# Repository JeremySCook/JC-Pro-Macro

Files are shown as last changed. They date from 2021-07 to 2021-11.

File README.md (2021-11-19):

# JC-Pro-Macro

Macro keypad and rotary input based on the ATmega32U4 Pro Micro

Enhanced JC Pro Macro 2: https://github.com/JeremySCook/JC-Pro-Macro-2/

**!! After initial install, GND and RST pins may need to be shorted together  
momentarily to reset after hitting upload in the Arduino IDE for reprogramming.  
Quickly resetting twice in sequence may give you more time to load the program !!**

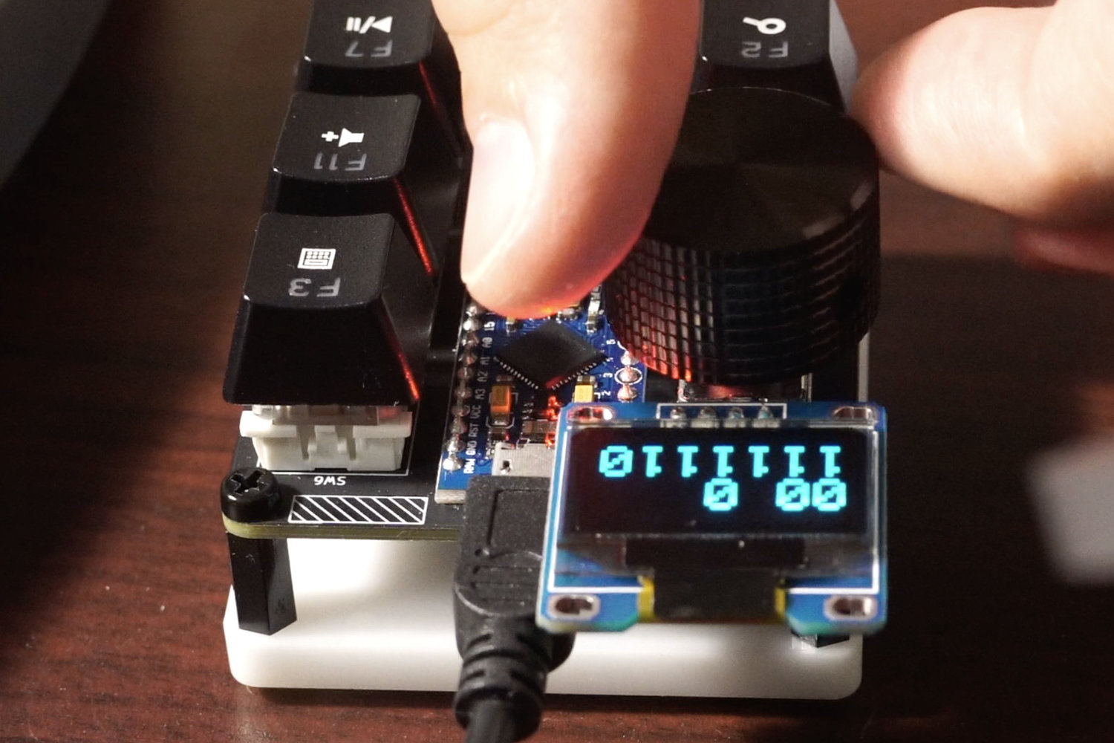
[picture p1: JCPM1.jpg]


# Videos:

Development:       https://www.youtube.com/watch?v=g-XJLiv03rI  
Assembly process:  https://www.youtube.com/watch?v=au07GKwa_J8

# Info

Available on Tindie: https://www.tindie.com/products/24327

I2C pins are broken out and arranged for use with SSD1306-based OLED screens  
Current program includes diagnostic code for this type of screen.  
2 additional GPIO pins, as well as GND and +5V are broken out, giving a total  
of 4 GPIO pins that can be used to control external devices (perhaps a small fan)



Uses HID Project software by NicoHood: https://github.com/NicoHood/HID  
My previous rotary input project: https://github.com/JeremySCook/RotaryControl



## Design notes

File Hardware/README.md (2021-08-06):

Assembly video: https://www.youtube.com/watch?v=VwfGT706jW0

Items required:

JC Pro Macro Board [Tindie](https://www.tindie.com/products/24327)  
EC11 - style rotary encoder [Amazon](https://amzn.to/2UHf1wW)  
KeySwitches - [Amazon](https://amzn.to/3iFpGQH)  
"Arduino" Pro Micro - [Amazon](https://amzn.to/2UALftK)

Depending on preference, and for potentially better performance, user may choose to desolder  
or otherwise **disable LEDs** (or lack thereof) on the Pro Micro as shown below:

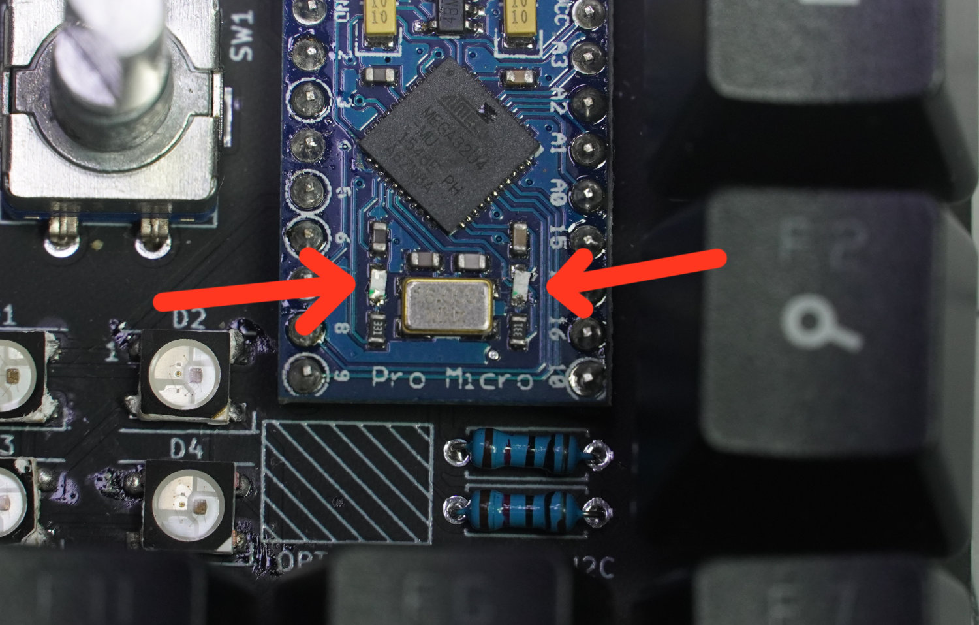
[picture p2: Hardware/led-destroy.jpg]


A variety of keyswitches and encoders will work, examples are provided for your reference.
The Pro Micro is available on Tindie, along with some other components.

As shown in the video, you can even take apart a keyboard to harvest parts if you like.

Amazon links are affiliate, meaning I get a small percentage of sales.

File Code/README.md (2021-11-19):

## Programming

**!! After initial install, GND and RST pins may need to be shorted together  
momentarily to reset after hitting upload in the Arduino IDE for reprogramming.
Quickly resetting twice in sequence may give you more time to load the program !!**

## Standard Code

Current standard code (ProMacroStandard.ino) is written and tested on a Macintosh -  
should work with a PC or Linux, possibly with some modifications.

Includes a mode for media control and browser tabbing, as well as a "jiggle" mode to keep your computer awake.
Switch modes by simultaneously pressing upper-right key, and the key directly below that.

Also, due to differences in manufacture, line 50:

Encoder myEnc(0,1); //if rotation is backwards, swap 0 and 1

may need to be swapped as noted depending on the encoder

## Alternative Modes Slihter.io Mode & FCPX

Additional modes are included in the standard code and can be accessed by modifying the array shown below. Modes  
will switch from the 0 indexed number in the array, to the next one and so forth. So if you want your controller to  
go: volume-jiggle-slither, change it to {0, 1, 2}. volume-FCPX would be {0, 3}. All current modes would be {0, 1, 2, 3, 4}



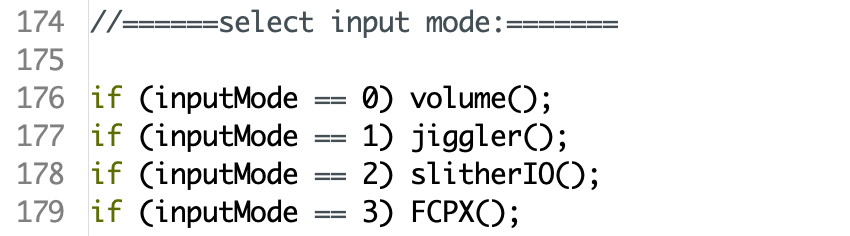
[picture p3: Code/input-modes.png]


In slither mode, align the mouse with the head of worm and press upper-right keyboard button. You can then steer the 
worm with the encoder and speed up with the three bottom buttons. There's also a "NASCAR" mode where the worm keeps
turning left.

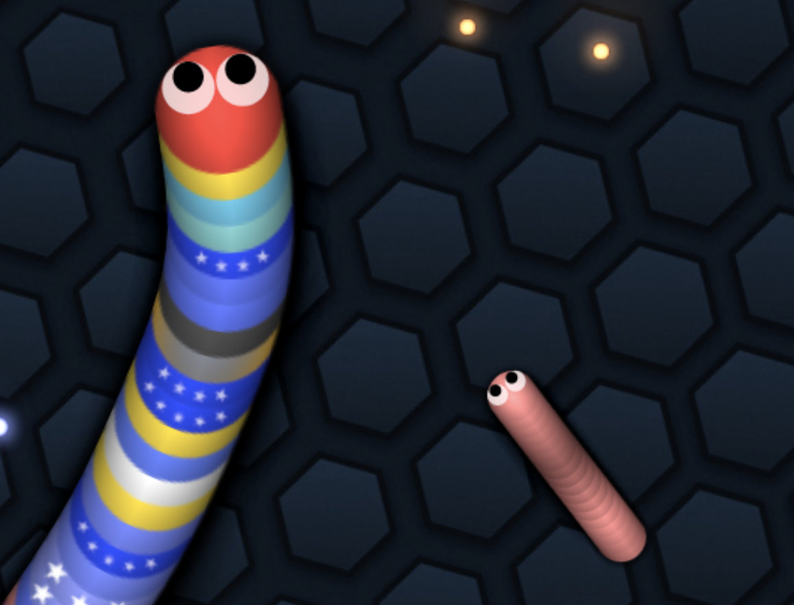
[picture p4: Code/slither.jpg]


In FCPX mode, encoder advances/rewinds frames, bottom buttons stop ffwd/rev, top right and below zoom in and out. Press
the encoder to break all clips. Great for trimming extra footage.

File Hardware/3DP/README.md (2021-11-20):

JC Pro Macro Model.step is the assembly 3D file that is openable in a variety of CAD packages.  
Not particularly "clean" but potentially good for reference if you want to build on the design.

**3D printed accessories for JCPM**

* 3DP-base - can be used as a base instead of standoffs and laser cut acrylic - may need work on tabs.
* Assembl-Jig - used to facilitate assembly of device
* Knob - 3D-printed knob for EC11 encoder
* PR-giganto-knob - as pictured below, made by [Pat Regan](https://twitter.com/patsheadcom) via [customizer](https://www.thingiverse.com/thing:2220561)
* 3DP-base_m3_heatset_flaszlo11.stl, made by flaszlo11

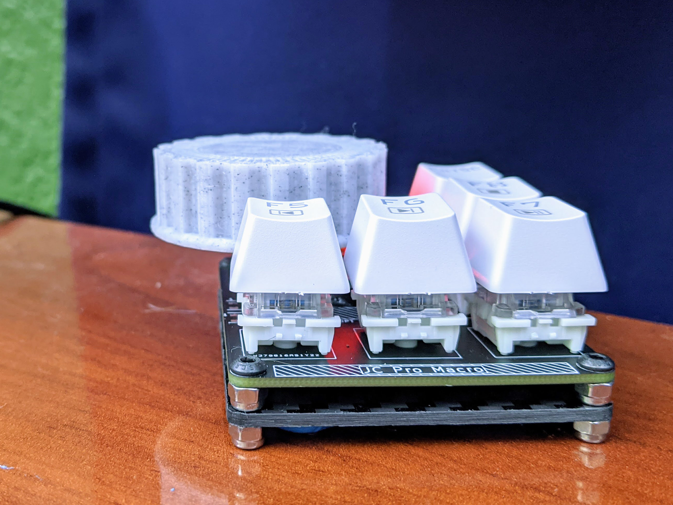
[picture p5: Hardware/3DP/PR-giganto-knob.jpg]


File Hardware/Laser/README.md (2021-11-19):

Laser cut base options for LightBurn (outline is slightly larger than board)

DXF is the board layout itself.

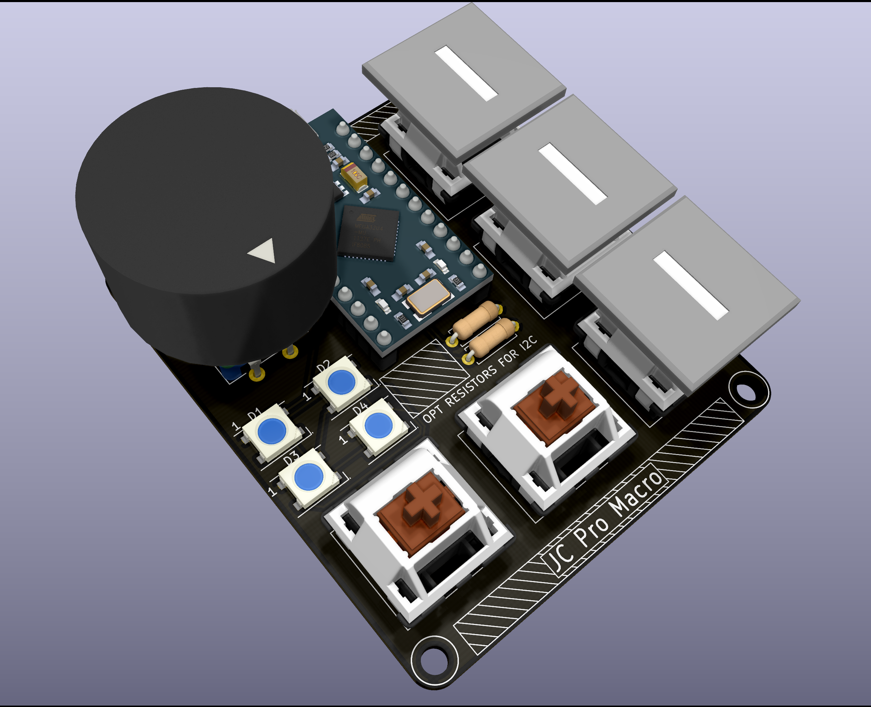
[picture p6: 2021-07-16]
JCPMRender.png

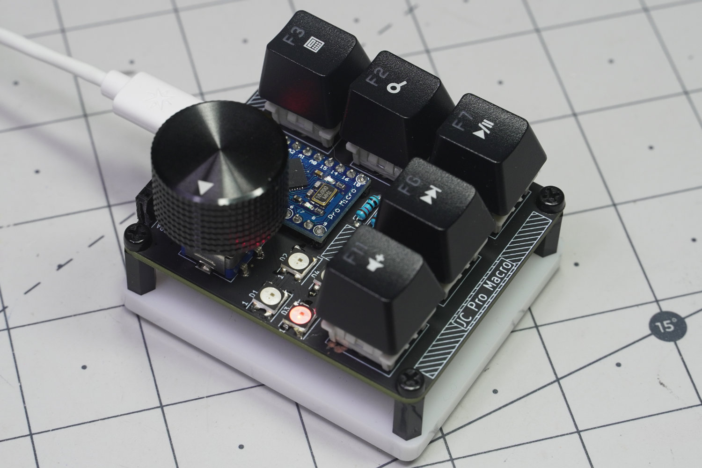
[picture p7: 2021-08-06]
JCPM2.jpg

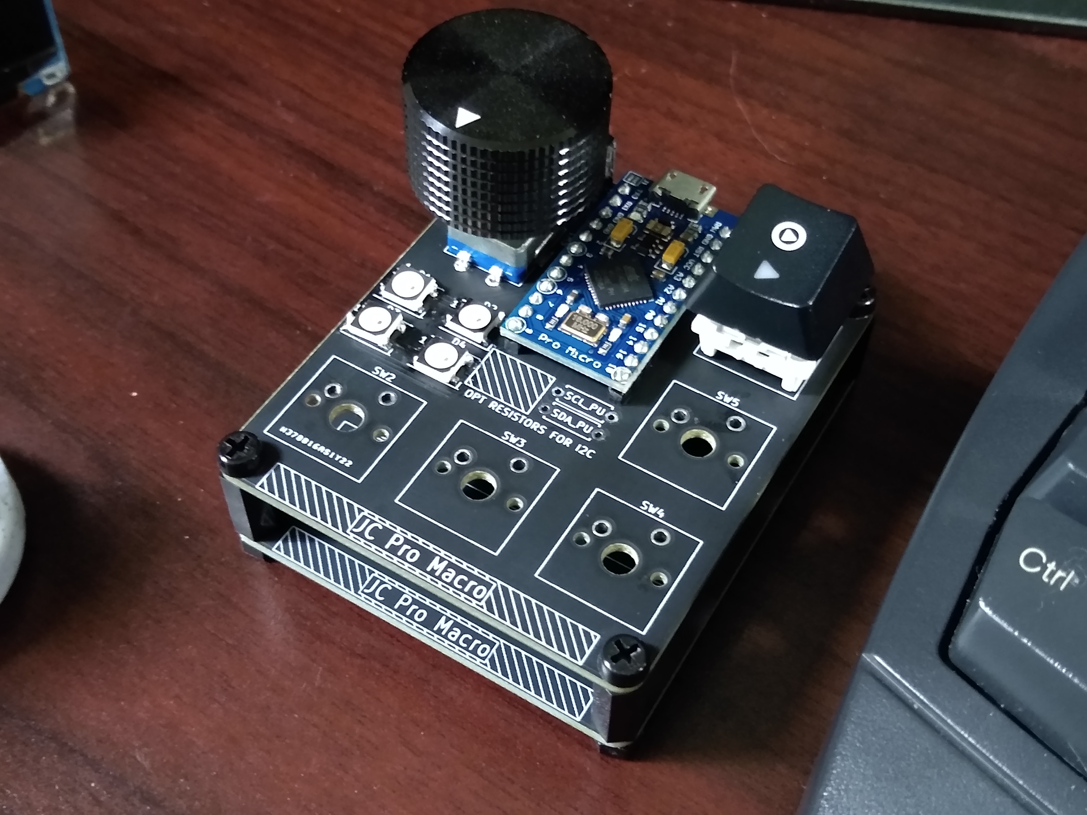
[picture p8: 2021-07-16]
JCPMPartAssy.jpg

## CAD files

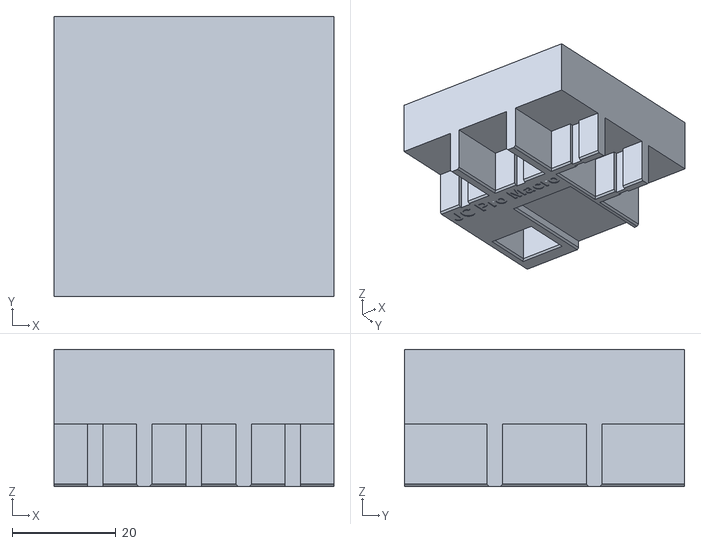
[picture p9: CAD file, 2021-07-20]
Hardware/3DP/Assembly-Jig.stl
54.0 x 54.1 x 26.5

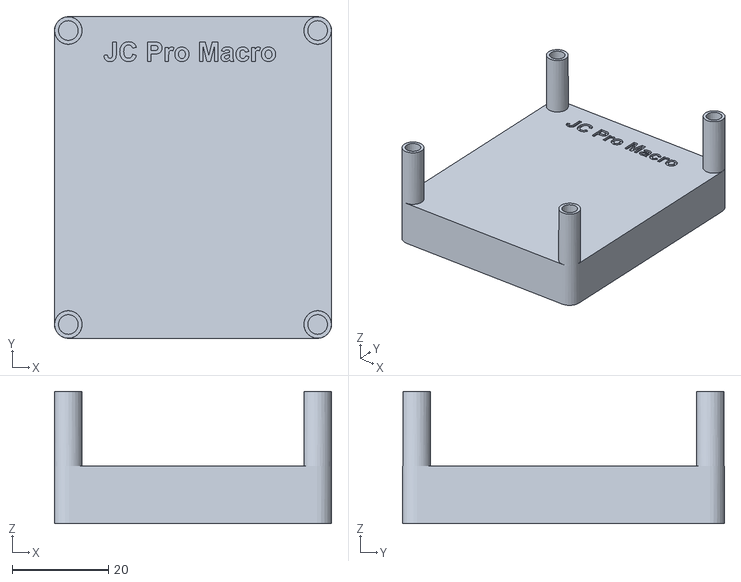
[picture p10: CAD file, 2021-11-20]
Hardware/3DP/3DP-base_m3_heatset_flaszlo11.stl
57.7 x 67.0 x 27.5

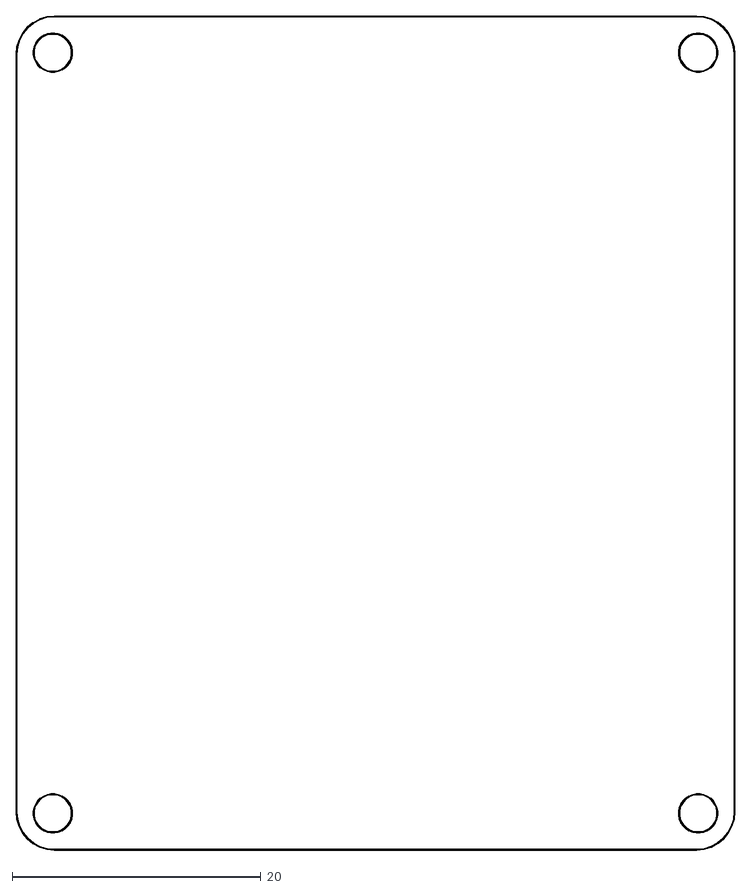
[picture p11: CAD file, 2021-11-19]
Hardware/Laser/JC Pro Macro Board Cuts.dxf
57.8 x 67.0

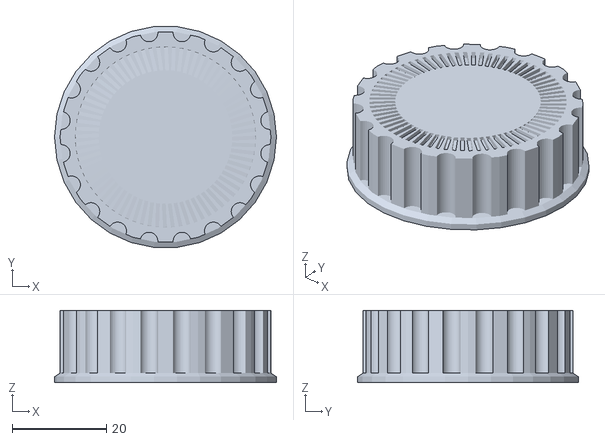
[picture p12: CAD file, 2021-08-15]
Hardware/3DP/PR-gitanto-knob.stl
47.0 x 46.7 x 15.2

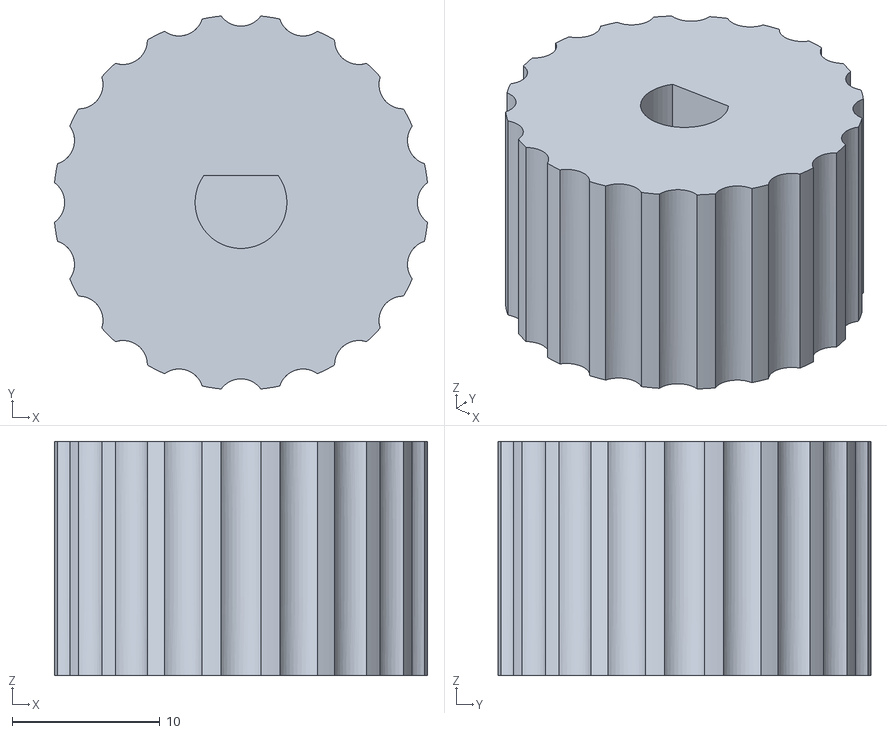
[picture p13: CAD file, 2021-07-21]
Hardware/3DP/Knob.stl
25.3 x 25.3 x 15.9

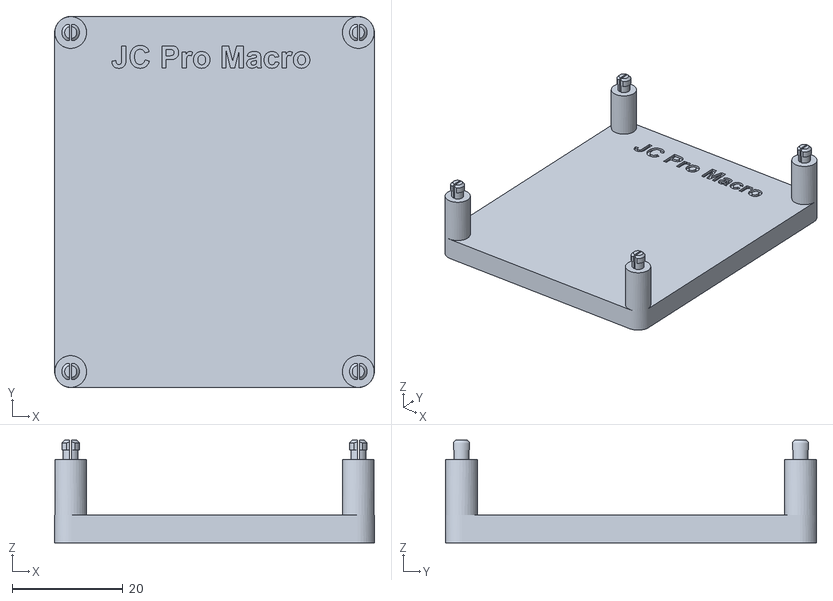
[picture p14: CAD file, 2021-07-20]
Hardware/3DP/3DP-base.stl
57.7 x 67.0 x 18.5

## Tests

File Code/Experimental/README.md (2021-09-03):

## Experimental Code

## Experimental Music Mode

ProMacro-6-music.ino allows you to connect a small speaker to GPIO pin 7 to play a number of notes.
Demo: https://twitter.com/JeremySCook/status/1423705079153139716

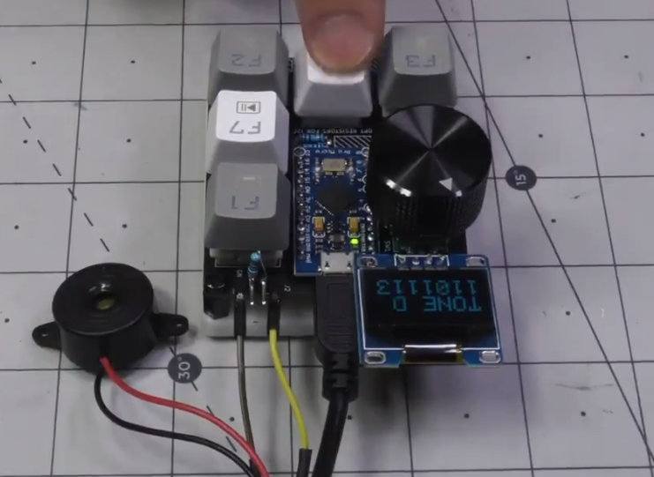
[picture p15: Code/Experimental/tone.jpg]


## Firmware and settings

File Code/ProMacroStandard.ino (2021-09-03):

//Example for JC Pro Macro board
//set up to work in Mac OS
//Includes support for 1306 display
//Reference: https://github.com/NicoHood/HID/blob/master/src/KeyboardLayouts/ImprovedKeylayouts.h
//Reference: https://arduinogetstarted.com/tutorials/arduino-button-long-press-short-press 
//
//To do:
//Figure out what to do with bottom support - remake offset so locks in?
//caps lock code? - does not work properly on Mac it seems

//========================================================

#include <SPI.h>
#include <Wire.h>

// Declare variables etc=========================================

bool SW1 = 1; //encoder button
bool SW2 = 1; //lower-left keyswitch
bool SW3 = 1;
bool SW4 = 1; //lower-right keyswitch
bool SW5 = 1;
bool SW6 = 1; //upper-right keyswitch
bool increment = 0;
bool decrement = 0;
long oldPosition;
long newPosition;
int inputMode = 0;
int LEDLight = 1;
int LEDCircle[4] = {0, 1, 3, 2};
int counter = 0;
bool nascar = 0;
long newNascarTurnTime = 0;
long oldNascarTurnTime = 0;
long newBeatTime = 0;
long oldBeatTime = 0;
bool beatOn = 0;

int fanSpeed = 0;
bool fanPulse = 0;
long newPulseTime = 0;
long oldPulseTime = 0;
int fanRPM = 0;
char toneNote;

int modeArray[] = {0, 1}; //adjust this array to modify sequence of modes - as written, change to {0, 1, 2, 3, 4, 5} to access all modes
int inputModeIndex = 0;
int modeArrayLength = (sizeof(modeArray) / sizeof(modeArray[0]));

// Encoder setup =============================================

#include <Encoder.h>
#include <HID-Project.h>
Encoder myEnc(0,1); //if rotation is backwards, swap 0 and 1

// Screen setup =============================================

#include <Adafruit_GFX.h>
#include <Adafruit_SSD1306.h>
#define SCREEN_WIDTH 128 // OLED display width, in pixels
#define SCREEN_HEIGHT 64 // OLED display height, in pixels
#define OLED_RESET     4 // Reset pin # (or -1 if sharing Arduino reset pin)
#define SCREEN_ADDRESS 0x3C ///< See datasheet for Address; 0x3D for 128x64, 0x3C for 128x32
Adafruit_SSD1306 display(SCREEN_WIDTH, SCREEN_HEIGHT, &Wire, OLED_RESET);

// NeoPixel setup =============================================

// NeoPixel Ring simple sketch (c) 2013 Shae Erisson
// Released under the GPLv3 license to match the rest of the
// Adafruit NeoPixel library

#include <Adafruit_NeoPixel.h>
#ifdef __AVR__
 #include <avr/power.h> // Required for 16 MHz Adafruit Trinket
#endif

// Which pin on the Arduino is connected to the NeoPixels?
#define PIN        5 // On Trinket or Gemma, suggest changing this to 1

// How many NeoPixels are attached to the Arduino?
#define NUMPIXELS 4 // Popular NeoPixel ring size

// When setting up the NeoPixel library, we tell it how many pixels,
// and which pin to use to send signals. Note that for older NeoPixel
// strips you might need to change the third parameter -- see the
// strandtest example for more information on possible values.
Adafruit_NeoPixel pixels(NUMPIXELS, PIN, NEO_GRB + NEO_KHZ800);

#define DELAYVAL 500 // Time (in milliseconds) to pause between pixels

//============================================================

void setup() {
  Serial.begin(9600);
  pinMode(4, INPUT_PULLUP); //SW1 pushbutton (encoder button)
  pinMode(15, INPUT_PULLUP); //SW2 pushbutton
  pinMode(A0, INPUT_PULLUP); //SW3 pushbutton
  pinMode(A1, INPUT_PULLUP); //SW4 pushbutton
  pinMode(A2, INPUT_PULLUP); //SW5 pushbutton
  pinMode(A3, INPUT_PULLUP); //SW6 pushbutton

  randomSeed(analogRead(A9));
     
  // SSD1306_SWITCHCAPVCC = generate display voltage from 3.3V internally
  if(!display.begin(SSD1306_SWITCHCAPVCC, SCREEN_ADDRESS)) {
    Serial.println(F("SSD1306 allocation failed"));
    for(;;); // Don't proceed, loop forever
  }
  display.setRotation(2); //sets rotation 1 through 4 (2 = 180º rotation vs 4)
  display.clearDisplay();
  // Draw text
  display.setTextSize(1);             // Normal 1:1 pixel scale
  display.setTextColor(SSD1306_WHITE);        // Draw white text
  display.setCursor(30,0);             // Start at top-left corner
  display.print("Hello, world!");
  display.setCursor(30,30);  
  display.print("test");
  display.display();
  delay(10);
  display.setTextSize(3); 

//setup keyboard and mouse input
//perhaps cound add in a delay so that you can program before this starts up
Mouse.begin();
Keyboard.begin();
//BootKeyboard.begin(); - BootKeyboard use appears to give problems w/ Macintosh


//NeoPixel setup=========================================

  pixels.begin(); // INITIALIZE NeoPixel strip object (REQUIRED)
  pixels.clear();


  for(int i=0; i<NUMPIXELS; i++){
    pixels.setPixelColor(i, pixels.Color(10, 0, 0));
  }
  pixels.show(); // Show results
}


void loop() {

  SW1 = digitalRead(4);
  SW2 = digitalRead(15);
  SW3 = digitalRead(A0);
  SW4 = digitalRead(A1);
  SW5 = digitalRead(A2);
  SW6 = digitalRead(A3);

  newPosition = myEnc.read();
  
  if (newPosition > (oldPosition + 2)) { 
    increment = 1;
    delay(5);
    oldPosition = myEnc.read();
  }
  if (newPosition < (oldPosition - 2)) {
    decrement = 1;
    delay(5);
    oldPosition = myEnc.read();
  }

//=========change mode=================

   if ((SW6 == 0) && (SW5 == 0)){ 
      if (inputModeIndex < modeArrayLength){
        inputModeIndex++;
        inputMode = modeArray[inputModeIndex];
      }
      if (inputModeIndex == modeArrayLength){
        inputModeIndex = 0;
        inputMode = modeArray[inputModeIndex];
      }
      SW6 = 1;
      SW5 = 1;
      delay(250);
    }

//================================

//screen(); //need to change to only call within functions

//======select input mode:=======

if (inputMode == 0) volume();
if (inputMode == 1) jiggler();
if (inputMode == 2) slitherIO();
if (inputMode == 3) FCPX();
if (inputMode == 4) fan();
if (inputMode == 5) music();

//Serial.println(inputMode);

}

void volume(){ //works with new code

  if (increment == 1) {
        Consumer.write(MEDIA_VOLUME_UP);
        if (LEDLight == 3) LEDLight = 0;
        else if (LEDLight < 3) LEDLight += 1;
        pixels.clear();
        pixels.setPixelColor(LEDCircle[LEDLight], pixels.Color(10, 0, 0));
        pixels.show(); // Show results
        increment = 0;
        decrement = 0;
        //delay(10);
      }
      
  if (decrement == 1) {
        Consumer.write(MEDIA_VOLUME_DOWN);
        if (LEDLight == 0) LEDLight = 3;
        else if (LEDLight > 0) LEDLight -= 1;
        pixels.clear();
        pixels.setPixelColor(LEDCircle[LEDLight], pixels.Color(10, 0, 0));
        pixels.show(); // Show results
        increment = 0;
        decrement = 0;
        //delay(10);
      }
  if (SW6 == 0){ //tab to next browser tab Firefox or Chrome
        Keyboard.press(KEY_LEFT_CTRL);
        Keyboard.press(KEY_TAB);          
        Keyboard.releaseAll();
        delay(50);
      }
  if (SW5 == 0){ //tab to previous browser tab Firefox or Chrome
        Keyboard.press(KEY_LEFT_SHIFT);
        Keyboard.press(KEY_LEFT_CTRL);
        Keyboard.press(KEY_TAB);
        Keyboard.releaseAll();
        delay(50);
      }
  if (SW4 == 0) {
        Consumer.write(MEDIA_PLAY_PAUSE); 
        delay(100);
      }
  if (SW3 == 0) {
        Consumer.write(MEDIA_NEXT);
        delay(50);
      }
  if (SW2 == 0) {
        Consumer.write(MEDIA_PREVIOUS);
        delay(50);
      }
screen();
}

void jiggler(){ //works with new code
  
  Serial.print("commence to jiggling");
      //Consumer.write(MEDIA_VOLUME_UP);
      //Consumer.write(MEDIA_VOLUME_DOWN);
      long randNumber = random(-50, 50);
      long randNumber1 = random(-50, 50);
      long randNumber2 = random(-50, 50);
      Mouse.move(randNumber, randNumber1);
      delay(100);
      int xMap = map(randNumber, -50, 50, 0, 100);
      int yMap = map(randNumber1, -50, 50, 0, 100);
      int zMap = map(randNumber2, -50, 50, 0, 100);
      pixels.setPixelColor(0, pixels.Color(xMap, yMap, zMap));
      pixels.setPixelColor(2, pixels.Color(zMap,xMap,yMap));
      pixels.setPixelColor(1, pixels.Color(yMap, zMap, xMap));
      pixels.setPixelColor(3, pixels.Color(xMap, zMap, yMap));           
      pixels.show(); // Show results

screenJiggle(); 
    
}

void slitherIO(){ //works with new code
//movement tracking
int xMovements[] = {-3, -8, -14, -16, -19, -19, -16, -14, -8, -3, 3, 8, 14, 16, 19, 19, 16, 14, 8, 3, -3};
int yMovements[] = {19, 16, 14, 8, 3, -3, -8, -14, -16, -19, -19, -16, -14, -8, -3, 3, 8, 14, 16, 19, 19};
int multiplier = 2; //changes speed of rotation

//homing routine =====================================================  
  if (SW6 == 0){
    Mouse.move(40, 10); //was 60, 0 before
    counter = 0;
    delay(250);
  }

//mouse move routine==================================================

  if (increment == 1) {
    //need a routine to loop back to zero etc to loop around the x/y movements for each increment

      for(int i=0; i< multiplier; i++){
        if (counter == 20) counter = 1;
        else if (counter < 20) ++counter;
        Mouse.move(xMovements[counter], yMovements[counter]);
        
        Serial.print(counter); Serial.print(" "); Serial.print(xMovements[counter]); Serial.print(" "); Serial.println(yMovements[counter]);
        increment = 0;
        decrement = 0;
      }
  }
  

    if (decrement == 1) { //increment and decrement work fine individually, but don't line up when reversed
      for(int i=0; i< multiplier; i++){     
        if (counter == 0) counter = 19; 
        else if (counter > 0) --counter;       
        Mouse.move(-xMovements[counter+1], -yMovements[counter+1]);

        Serial.print(counter); Serial.print(" "); Serial.print(-xMovements[counter+1]); Serial.print(" "); Serial.println(-yMovements[counter+1]);
        increment = 0;
        decrement = 0;
      }
  }

//worm speed input==============================

if ((SW2 == 0)||(SW3 == 0)||(SW4 ==0)){
        Keyboard.press(HID_KEYBOARD_SPACEBAR);       
        delay(5);
}

if ((SW2 == 1) && (SW3 == 1) && (SW4 == 1)){
        Keyboard.releaseAll();
        delay(5);
}

//worm auto turn input - NASCAR mode: all left turns

if ((SW5 == 0) && (nascar == 0)){
  nascar = 1;
  delay(20);
}

else if ((SW5 == 0) && (nascar ==1)){
  nascar = 0;
  delay(20);
}

if (nascar == 1){
  newNascarTurnTime = millis();
  if ((newNascarTurnTime - oldNascarTurnTime) > 200){
    decrement = 1;
    oldNascarTurnTime = newNascarTurnTime;
  }
}


screen();
  
}

void FCPX(){ //works with new code
  
  if (increment == 1) {
        //Keyboard.press(KEY_K);
        //Keyboard.releaseAll();       
        Keyboard.press(HID_KEYBOARD_RIGHTARROW);
        Keyboard.releaseAll();
        if (LEDLight == 3) LEDLight = 0;
        else if (LEDLight < 3) LEDLight += 1;
        pixels.clear();
        pixels.setPixelColor(LEDCircle[LEDLight], pixels.Color(0, 10, 0));
        pixels.show(); // Show results
        increment = 0;
        decrement = 0;
        //delay(50);
      }
      
  else if (decrement == 1) {
        //Keyboard.press(KEY_K);
        //Keyboard.releaseAll();  
        Keyboard.press(HID_KEYBOARD_LEFTARROW);
        Keyboard.releaseAll();
        if (LEDLight == 0) LEDLight = 3;
        else if (LEDLight > 0) LEDLight -= 1;
        pixels.clear();
        pixels.setPixelColor(LEDCircle[LEDLight], pixels.Color(0, 10, 0));
        pixels.show(); // Show results
        increment = 0;
        decrement = 0;
        //delay(50);
      }
  else if (SW6 == 0){ //Zoom in
        Keyboard.press(KEY_LEFT_WINDOWS);
        Keyboard.press(HID_KEYBOARD_EQUALS_AND_PLUS);    
        Keyboard.releaseAll();
        delay(50);
      }
  else if (SW5 == 0){ //Zoom out
        Keyboard.press(KEY_LEFT_WINDOWS);
        Keyboard.press(HID_KEYBOARD_MINUS_AND_UNDERSCORE);    
        Keyboard.releaseAll();
        delay(50);
      }
  else if (SW4 == 0) { //fwd
        Keyboard.press(KEY_L);
        Keyboard.releaseAll();
        delay(50);
      }
  else if (SW3 == 0) { //stop
        Keyboard.press(KEY_K);
        Keyboard.releaseAll();
        delay(50);
      }
  else if (SW2 == 0) { //BACK
        Keyboard.press(KEY_J);
        Keyboard.releaseAll();
        delay(50);
      }
  else if (SW1 == 0) { //break all win + shift + b
        Keyboard.press(KEY_LEFT_WINDOWS);        
        Keyboard.press(KEY_LEFT_SHIFT);
        Keyboard.press(KEY_B);        
        Keyboard.releaseAll();
        delay(50);
      }
screenFCPX();
}

void fan(){
  if (SW6 == 0){
    if (fanSpeed < 5){
    ++fanSpeed;
    }
    delay(20);
  }
  if (SW5 == 0){
    if (fanSpeed > 0){
    --fanSpeed;
    }
    delay(20);
  }
int fanSpeedScaled = map(fanSpeed, 0, 5, 0, 255);
analogWrite(6, fanSpeedScaled);
//Serial.print(fanSpeed); Serial.print(" "); Serial.println(fanSpeedScaled);

if(fanPulse == 0){
  newPulseTime = millis();
  fanRPM = (newPulseTime - oldPulseTime);
  oldPulseTime = newPulseTime;
}

screenFan();

}

void music(){

//attach small buzzer to pin 6 on aux jack
//

pinMode(7, OUTPUT);
digitalWrite(7, LOW);

  if (SW6 == 0){
    tone(6, 440, 100); //A4
    toneNote = 'A';
  }
  else if (SW5 == 0){
    tone(6, 494, 100); //B4
    toneNote = 'B';
  }
  else if (SW4 == 0){
    tone(6, 523, 100); //C5
    toneNote = 'C';
  }  
  else if (SW3 == 0){
    tone(6, 587, 100); //D5
    toneNote = 'D';
  }
  else if (SW2 == 0){
    tone(6, 659, 100); //E5
    toneNote = 'E';
  }
  else {
    toneNote = ' ';
  }
  
  if ((SW1 == 0) && (beatOn == 0)) {
    beatOn = 1;
    delay(100);
  }
  else if ((SW1 == 0) && (beatOn == 1)){
    beatOn = 0;
    delay(100);
  }
  
  if (beatOn == 1) {
  newBeatTime = millis();
  if ((newBeatTime - oldBeatTime) > 500){
  digitalWrite(7, HIGH);
  delay(35);
  digitalWrite(7, LOW);
    oldBeatTime = newBeatTime;
  }
  }

  if (decrement == 1){
  digitalWrite(7, HIGH);
  delay(35);
  digitalWrite(7, LOW);
  increment = 0;
  decrement = 0;
  }

  if (decrement == 1){
  digitalWrite(7, HIGH);
  delay(35);
  digitalWrite(7, LOW);
  increment = 0;
  decrement = 0;
  }

  if (increment == 1){
  digitalWrite(7, HIGH);
  delay(35);
  digitalWrite(7, LOW);
  increment = 0;
  decrement = 0;
  }
 
screenNote();
}

//======================.96" oled screen=======================

void screen(){
  display.clearDisplay();
  display.invertDisplay(0);
  display.setCursor(0,10);
  display.print(increment);
  display.print(decrement);
  display.print(" ");
  display.print(newPosition);
  display.println(LEDLight);
  display.print(SW1);
  display.print(SW2);
  display.print(SW3);
  display.print(SW4);
  display.print(SW5);
  display.print(SW6);
  display.print(inputMode);
  display.display();
  //Serial.println(SW1);
  //delay(10);
}

void screenFan(){
  display.clearDisplay();
  display.invertDisplay(0);
  display.setCursor(0,10);
  display.print("Fan ");
  display.print(fanSpeed);
  display.print(" ");
  display.println(fanPulse);
  display.print("T ");
  display.print(fanRPM);
  display.print(" ");
  display.print(inputMode);
  display.display();
  //Serial.println(SW1);
  //delay(10);
}

void screenJiggle(){
  display.clearDisplay();
  display.invertDisplay(0);
  display.setCursor(0,10);
  display.println("Rando");
  display.print("Mouse!");
  display.display();
}

void screenNote(){ //now used for notes
  display.clearDisplay();
  display.invertDisplay(0);
  display.setCursor(0,10);
  display.print("TONE ");
  display.println(toneNote);
  display.print(SW1);
  display.print(SW2);
  display.print(SW3);
  display.print(SW4);
  display.print(SW5);
  display.print(SW6);
  display.print(inputMode); 
  display.display();
  //Serial.println(SW1);
  //delay(10);
}

void screenFCPX(){
  display.clearDisplay();
  display.invertDisplay(0);
  display.setCursor(0,10);
  display.println("FCPX");
  display.print("Sh0rcut");
  display.display();
}
